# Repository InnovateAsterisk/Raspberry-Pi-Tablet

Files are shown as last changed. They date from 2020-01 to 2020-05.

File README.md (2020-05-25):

# Raspberry Pi Tablet

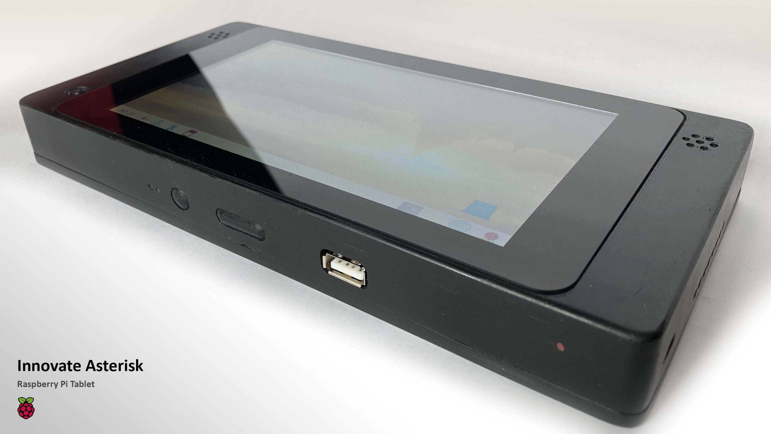
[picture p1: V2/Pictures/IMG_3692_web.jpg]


## Project Goals
To develop a 3D printable, Raspberry Pi based tablet. All parts (components) must be easy to obtain and readily available. It must have a battery, and it must be the primary source of power (meaning, it will charge up with a cable plugged in, but must have enough power to run without it.) It must be able to opperate perfect fine without a keyboard (meaning, everything in the user interface should work without an issue even if you dont have a keyboard and mouse plugged in.)

## Features
- **SBC :** Raspberry Pi version 4B+
- **Display :** 7 inch LCD Display (with touch)
- **Power Supply :** PiJuice UPS (with 5000 mAmp battery)
- **Camera :** Official Raspberry Pi 1080p Camera (front-facing)
- **Sound & Speakers:** Waveshare Audio HAT - powers 2 speakers, and 2 microphones, and provides an audio jack for headphones.
- **Accelerometer:** MPU-6050 Gyro/Accelerometer - to orientate the screen. (with python)
- **Cooling:** Fan connected to a Mosfet fan-speed controller (speed is controlled in python)
- **USB:** Breakout USB
- **Buttons:**
  - Power Button
  - Volume Up/Down rocker
- **LEDs**
  - Charge
  - Power and activity LED light is redirected (using nylon) to the case.
- **Backplate:** Bamboo wood back, with laser etched decal

## How To Video 
IMAGE ALT TEXT HERE (https://www.youtube.com/watch?v=wbJU22Zt_uo)

## Articles
- https://www.instructables.com/id/Raspberry-Pi-4B-3D-Printed-Tablet/
- https://www.hackster.io/news/innovate-asterisk-unveils-a-3d-printed-raspberry-pi-4-powered-tablet-be6d5298e047
- https://www.crackedconsole.com/2020/02/24/innovate-asterisk-unveils-a-3d-printed-raspberrypi-4-powered-tablet/

## Images
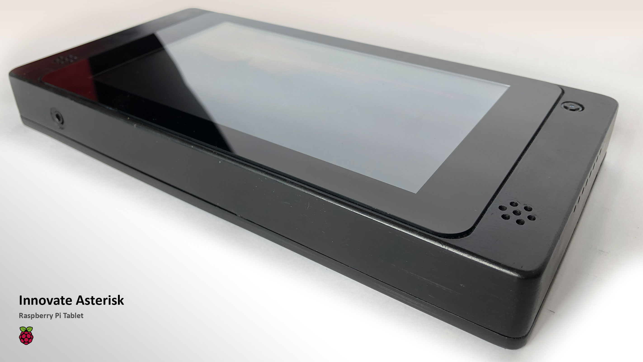
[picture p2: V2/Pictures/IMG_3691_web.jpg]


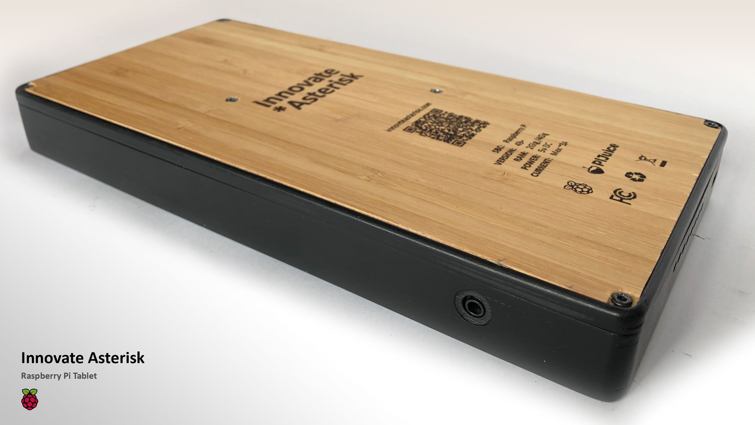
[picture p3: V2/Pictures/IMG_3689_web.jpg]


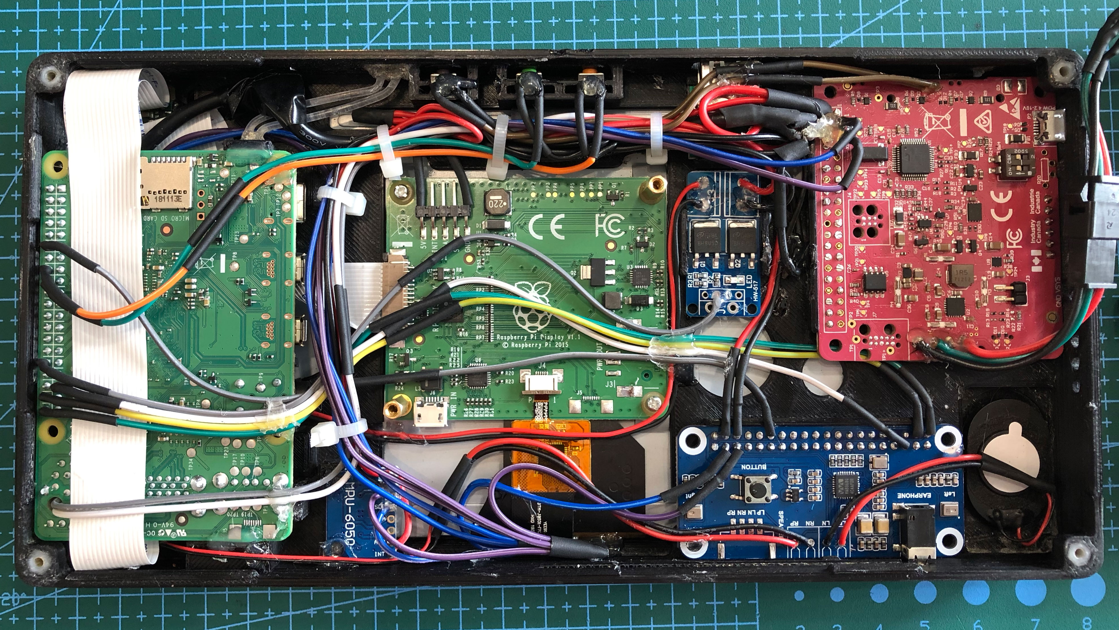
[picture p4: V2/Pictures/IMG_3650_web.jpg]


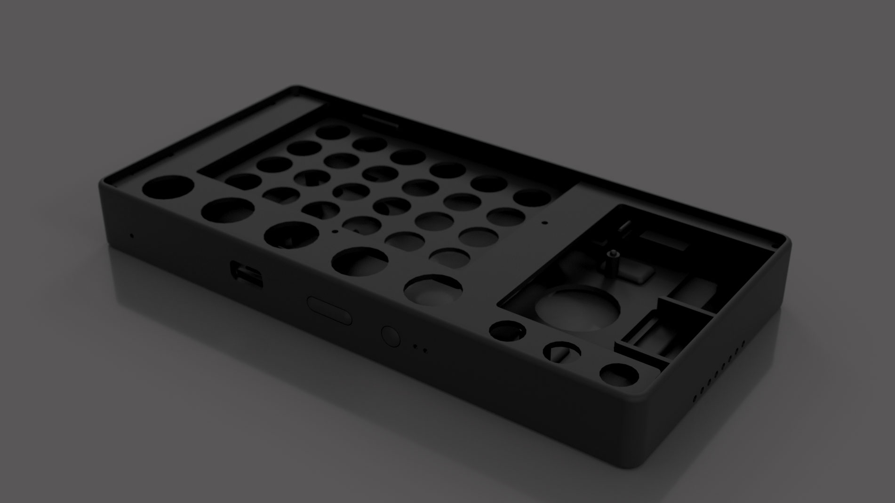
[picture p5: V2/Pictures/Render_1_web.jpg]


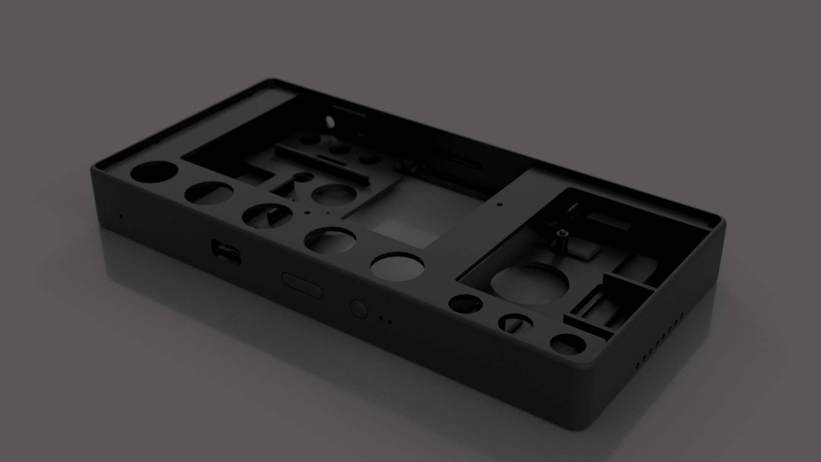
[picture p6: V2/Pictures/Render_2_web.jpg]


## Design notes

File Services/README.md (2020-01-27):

# Services

Various services will be needed in order to manage this device.

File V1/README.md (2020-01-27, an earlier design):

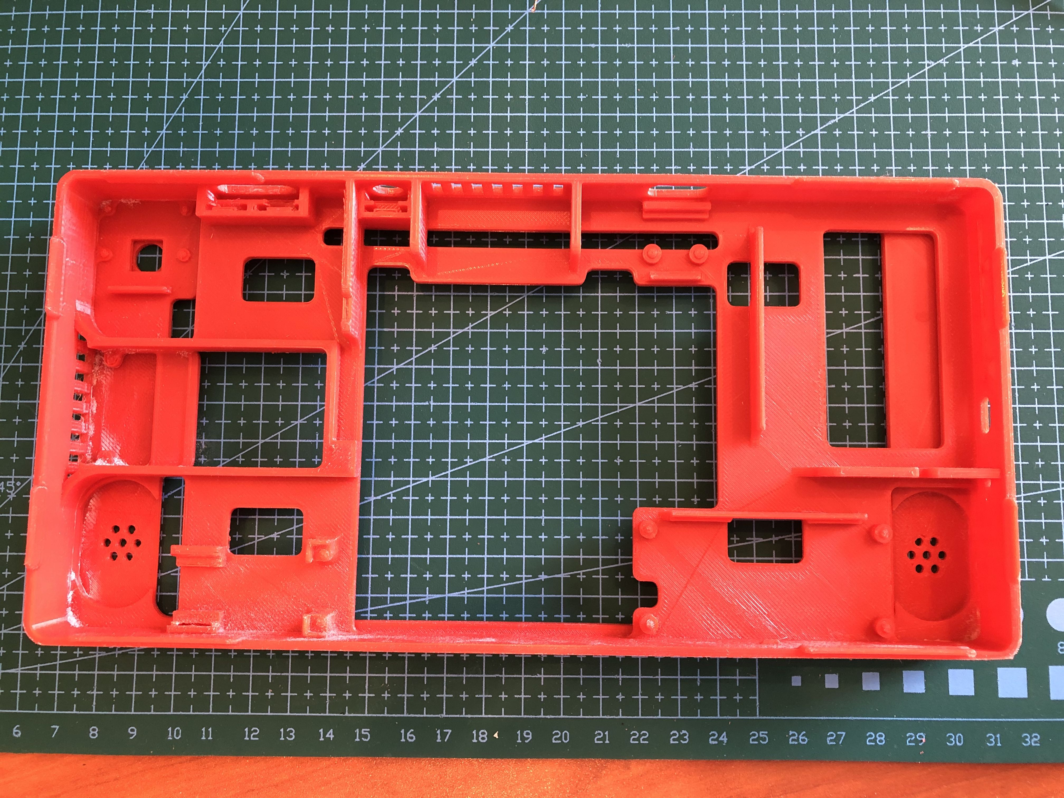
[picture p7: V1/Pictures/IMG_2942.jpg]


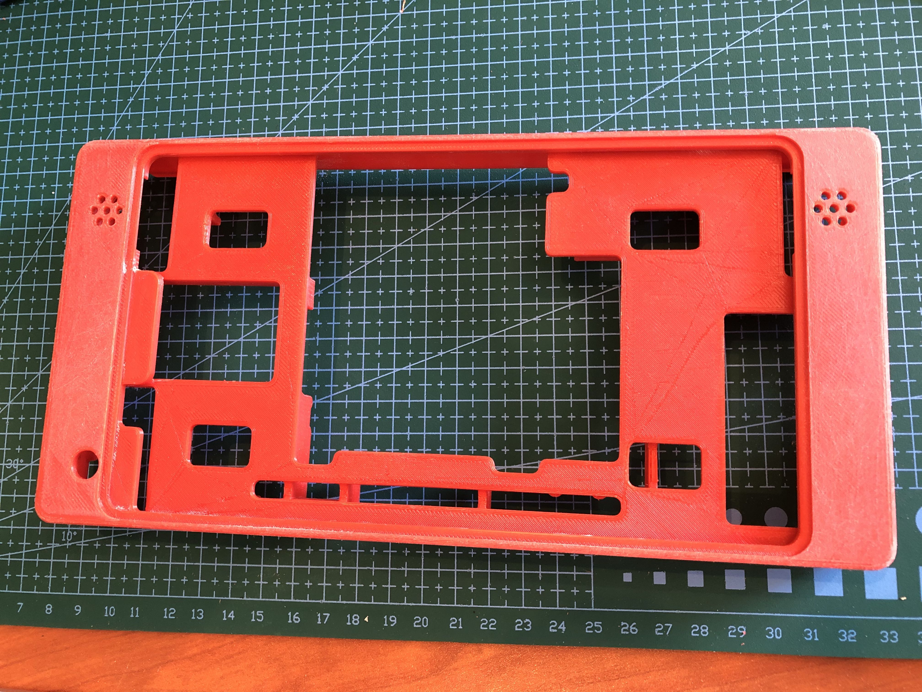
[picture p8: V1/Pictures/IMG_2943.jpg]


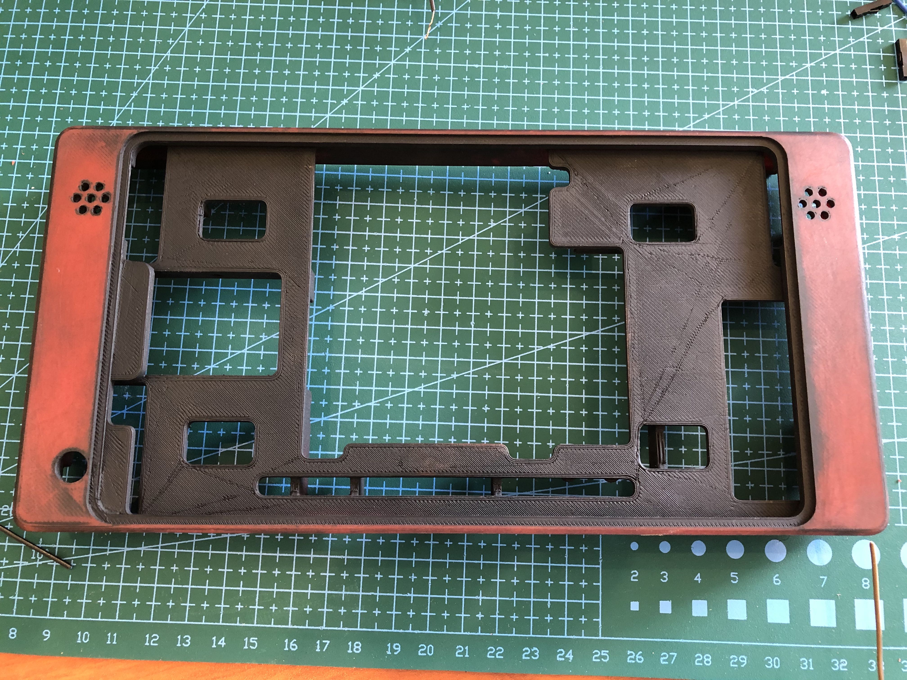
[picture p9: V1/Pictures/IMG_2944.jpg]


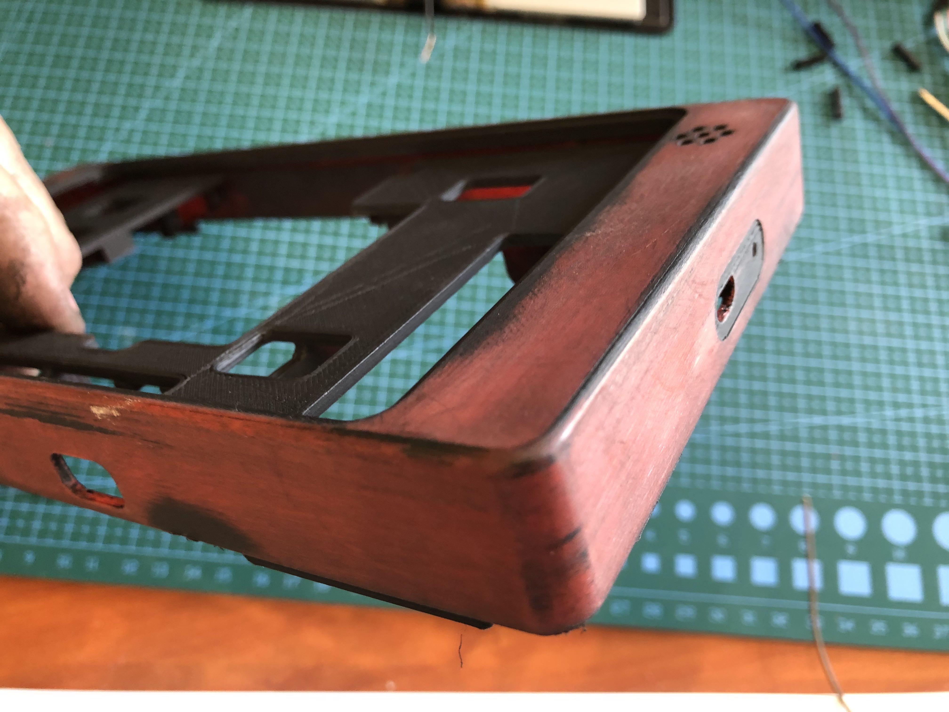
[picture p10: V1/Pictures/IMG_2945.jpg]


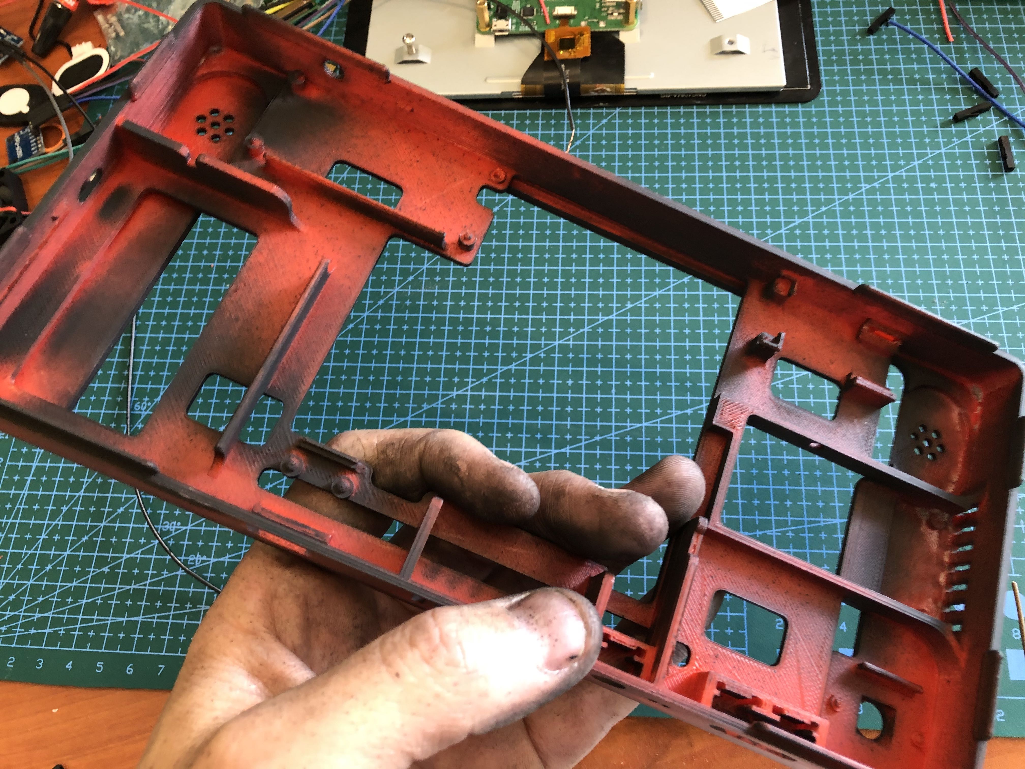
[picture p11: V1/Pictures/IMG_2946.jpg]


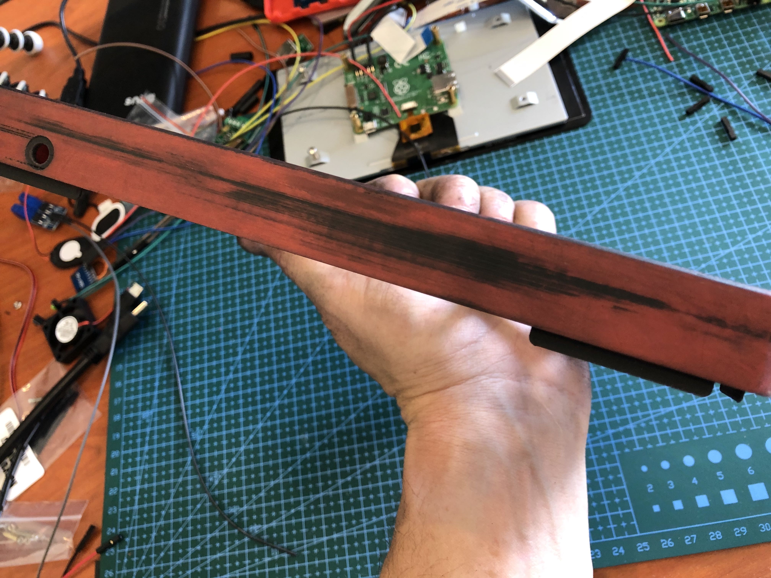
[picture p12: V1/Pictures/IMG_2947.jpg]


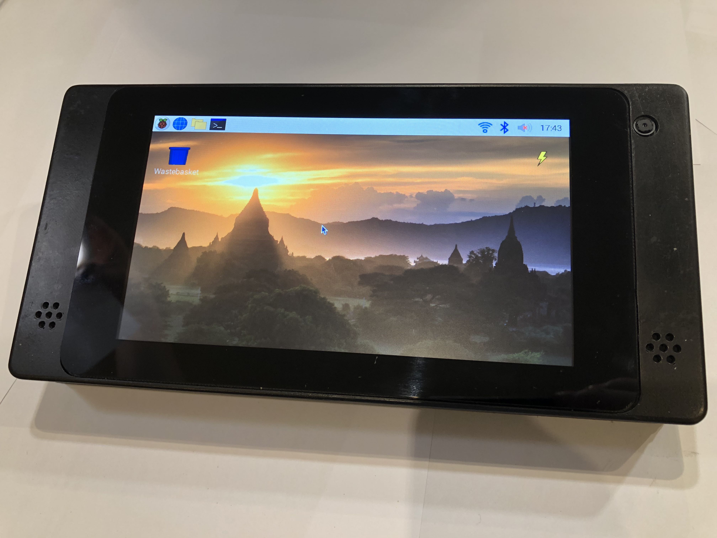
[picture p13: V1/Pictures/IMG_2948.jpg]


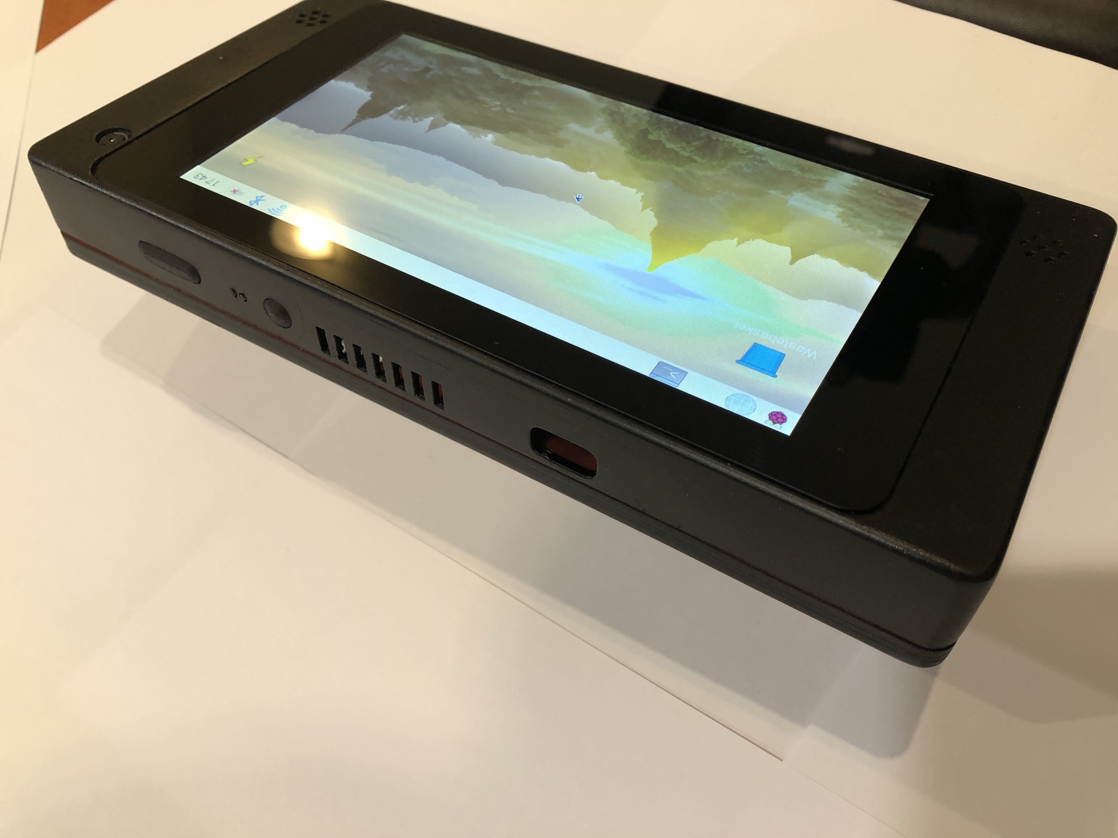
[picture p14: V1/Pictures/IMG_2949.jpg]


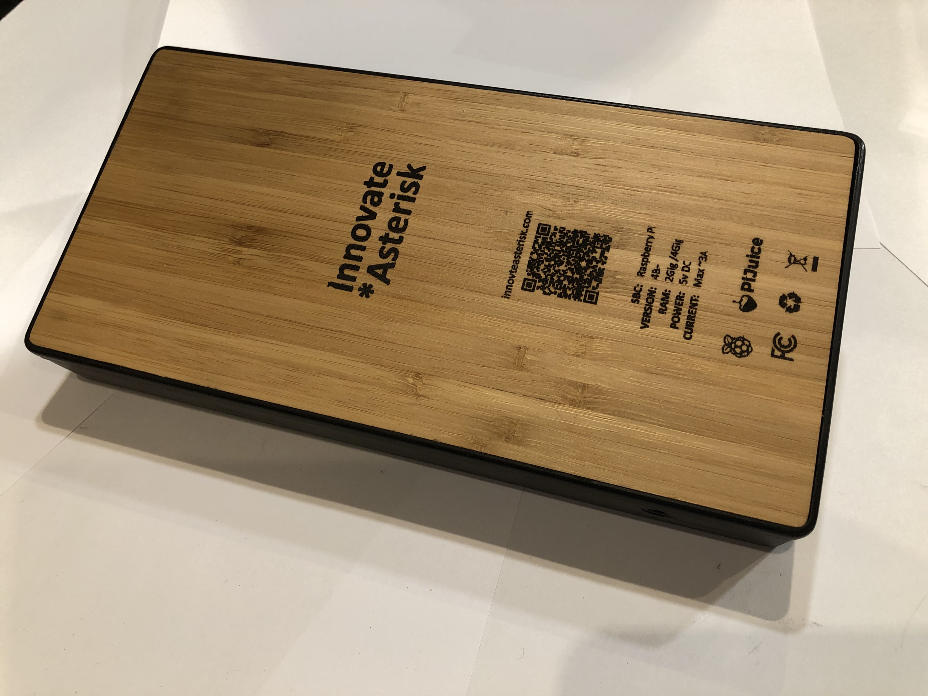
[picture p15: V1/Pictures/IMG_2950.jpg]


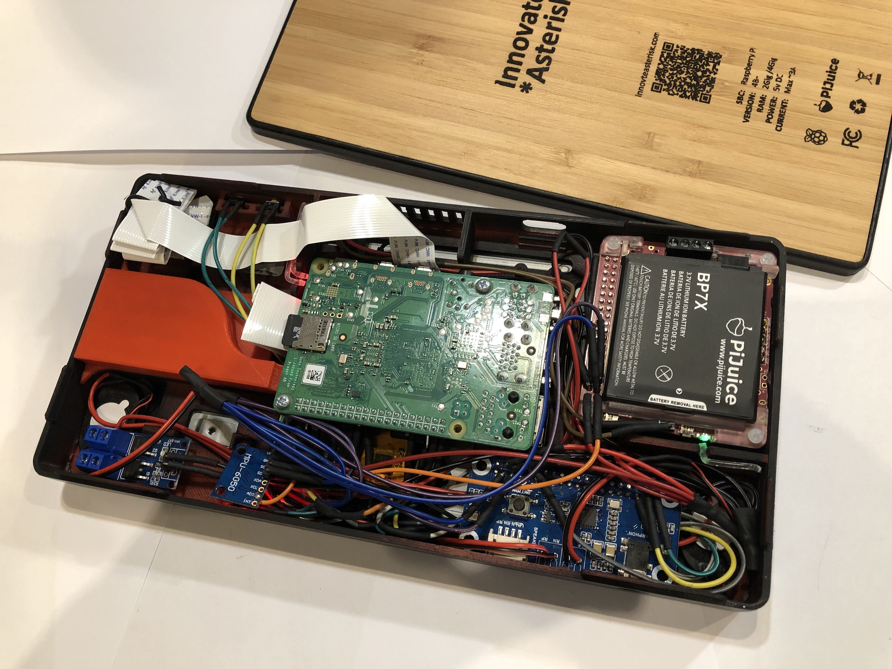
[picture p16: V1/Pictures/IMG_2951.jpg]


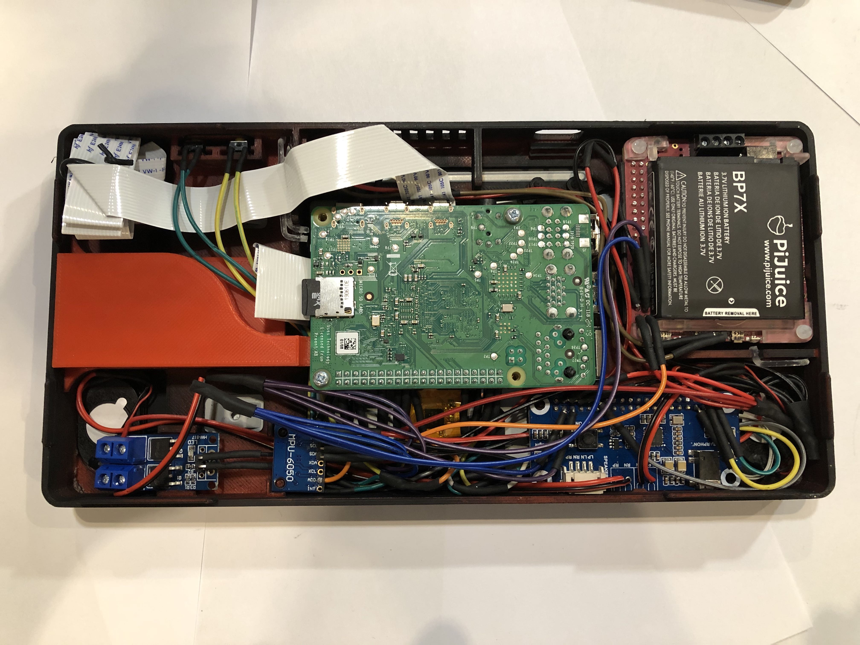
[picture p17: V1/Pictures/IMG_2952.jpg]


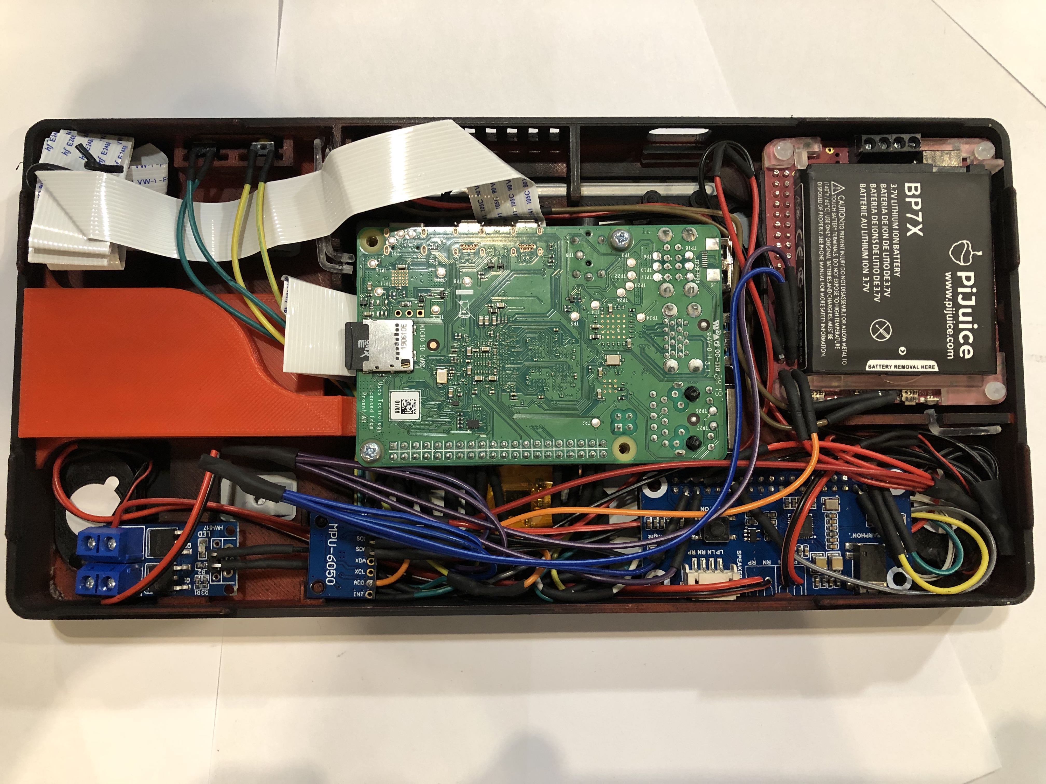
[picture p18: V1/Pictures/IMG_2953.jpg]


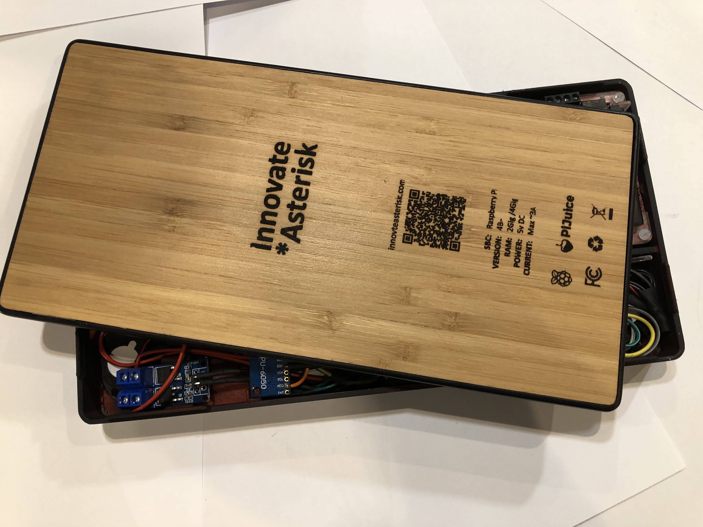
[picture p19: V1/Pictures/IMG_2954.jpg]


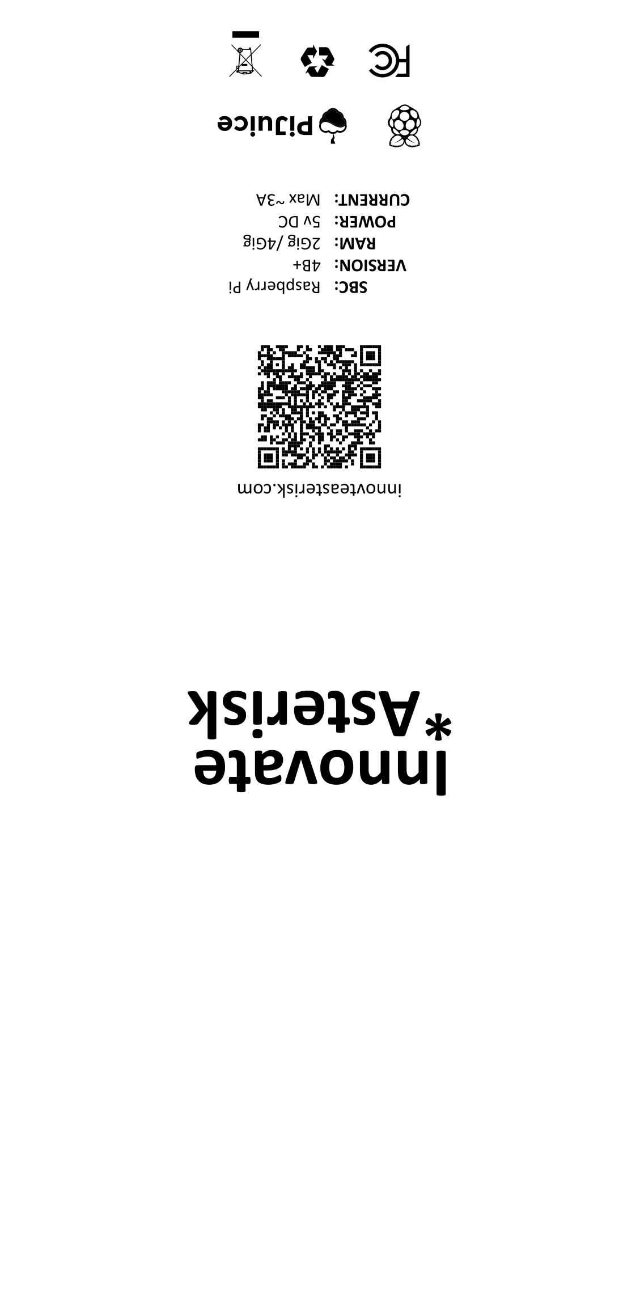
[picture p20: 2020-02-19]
Level_3_Wood/WoodDesign_ready.png

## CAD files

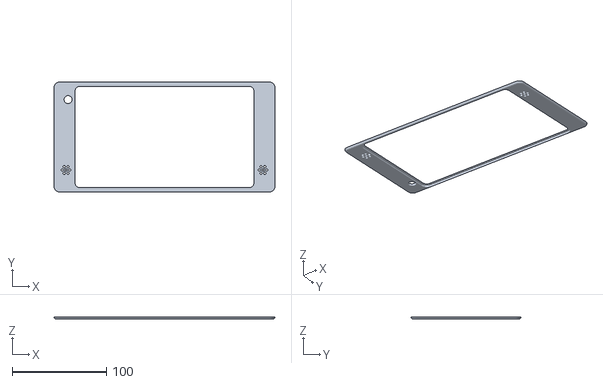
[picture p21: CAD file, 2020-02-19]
STL/Level_0.stl
234.4 x 116.6 x 2.20

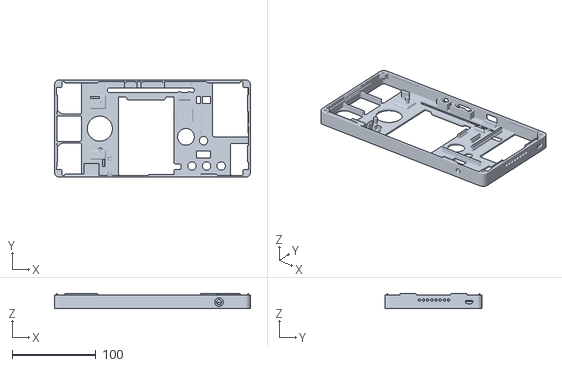
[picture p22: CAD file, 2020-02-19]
STL/Level_2.stl
234.4 x 116.6 x 17.8

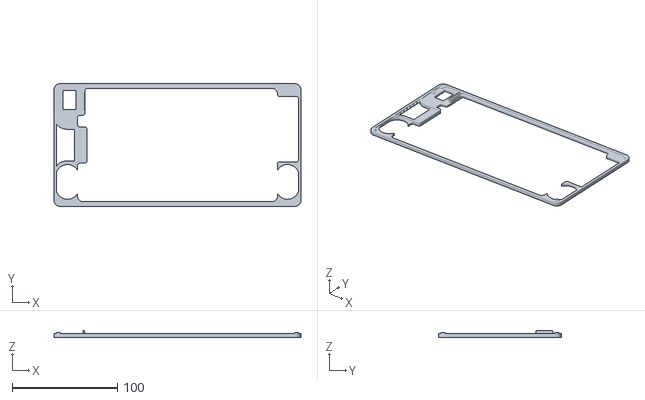
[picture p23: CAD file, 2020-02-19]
STL/Level_1.stl
234.4 x 116.6 x 6.77

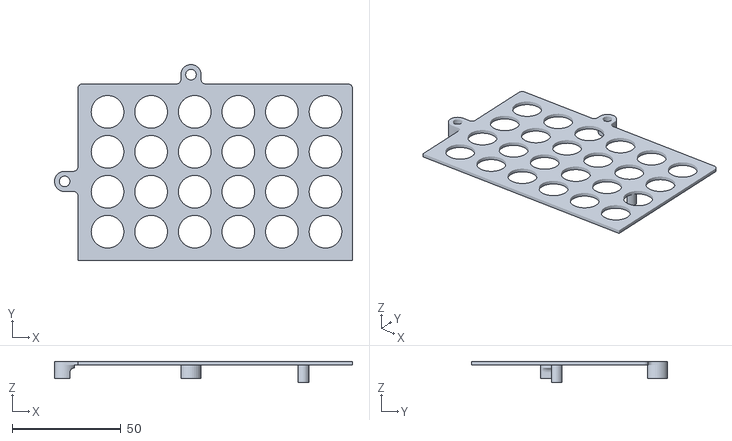
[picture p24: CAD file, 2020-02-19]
STL/Battery_Tray.stl
136.7 x 89.9 x 9.84

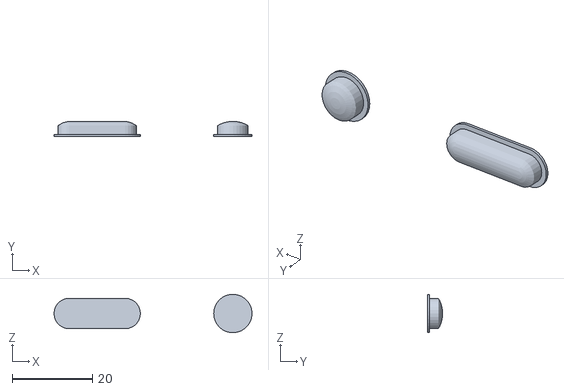
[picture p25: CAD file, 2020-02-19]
STL/Buttons.stl
49.5 x 3.70 x 9.59

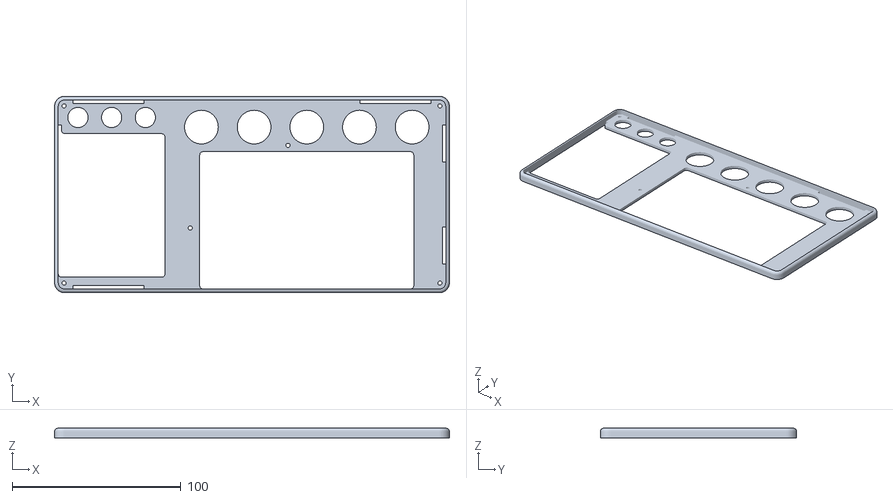
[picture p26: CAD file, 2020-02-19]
STL/Level_3.stl
234.4 x 116.6 x 5.70

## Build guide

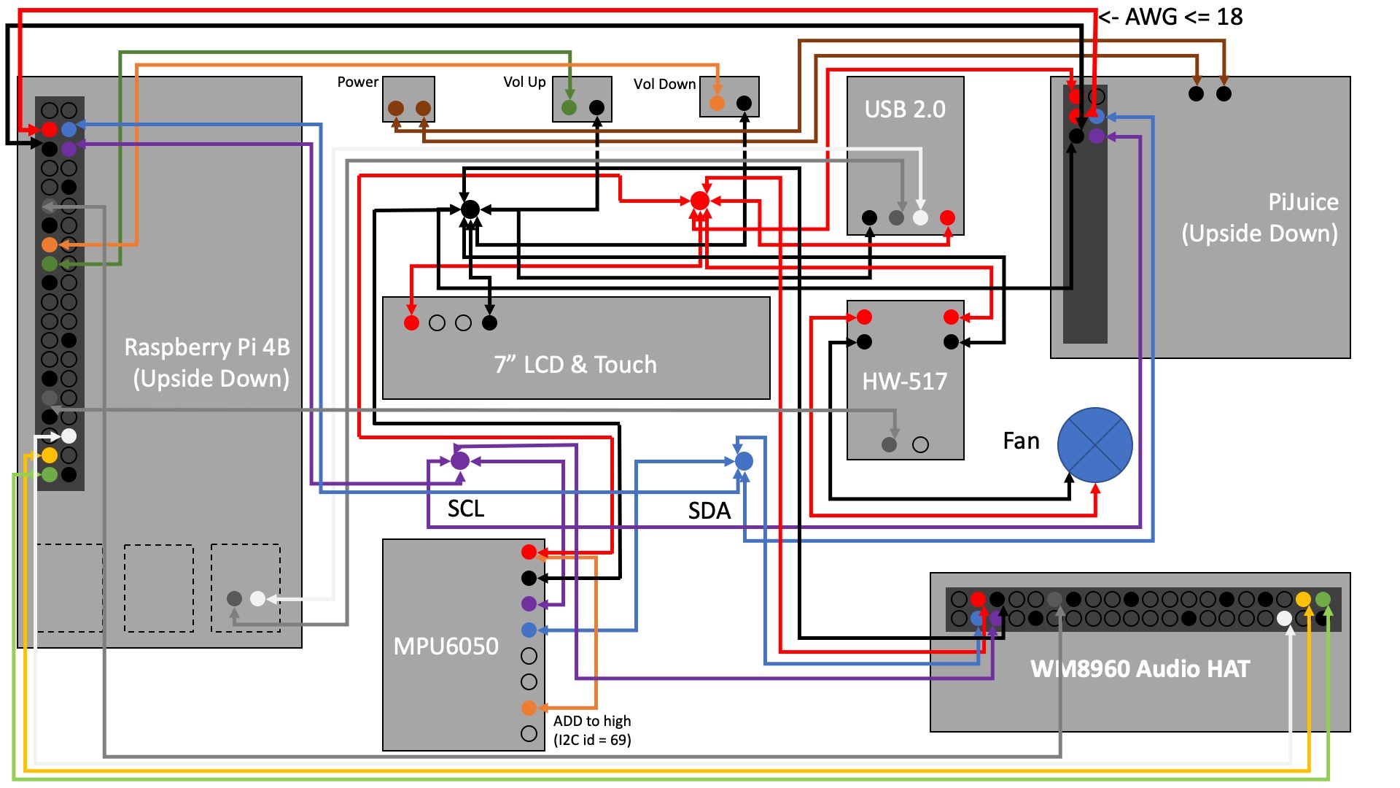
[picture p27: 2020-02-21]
Wiring Diagram/WiringDiagram.jpg

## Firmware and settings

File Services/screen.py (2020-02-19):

# Handles screen rotation using the Gyro
# ======================================

import smbus
import math
import time
import os

address = 0x69       # via i2cdetect (default is 68)

# Register https://www.i2cdevlib.com/devices/mpu6050#registers
PWR_MGMT_1   = 0x6B
SMPLRT_DIV   = 0x19
CONFIG       = 0x1A
GYRO_CONFIG  = 0x1B
ACCEL_CONFIG = 0x1C
INT_ENABLE   = 0x38
ACCEL_XOUT_H = 0x3B
ACCEL_YOUT_H = 0x3D
ACCEL_ZOUT_H = 0x3F
GYRO_XOUT_H  = 0x43
GYRO_YOUT_H  = 0x45
GYRO_ZOUT_H  = 0x47

# Pre-defined ranges
ACCEL_RANGE_2G = 0x00
ACCEL_RANGE_4G = 0x08
ACCEL_RANGE_8G = 0x10
ACCEL_RANGE_16G = 0x18

GYRO_RANGE_250DEG = 0x00
GYRO_RANGE_500DEG = 0x08
GYRO_RANGE_1000DEG = 0x10
GYRO_RANGE_2000DEG = 0x18

# Scale Modifiers
ACCEL_SCALE_MODIFIER_2G = 16384.0
ACCEL_SCALE_MODIFIER_4G = 8192.0
ACCEL_SCALE_MODIFIER_8G = 4096.0
ACCEL_SCALE_MODIFIER_16G = 2048.0

GYRO_SCALE_MODIFIER_250DEG = 131.0
GYRO_SCALE_MODIFIER_500DEG = 65.5
GYRO_SCALE_MODIFIER_1000DEG = 32.8
GYRO_SCALE_MODIFIER_2000DEG = 16.4

# Construct a SMBus
bus = smbus.SMBus(1)
bus.write_byte_data(address, PWR_MGMT_1, 0x00)
bus.write_byte_data(address, ACCEL_CONFIG, ACCEL_RANGE_2G)
bus.write_byte_data(address, GYRO_CONFIG, GYRO_RANGE_250DEG)

def read_byte(reg):
    return bus.read_byte_data(address, reg)

def read_word(reg):
    h = bus.read_byte_data(address, reg)
    l = bus.read_byte_data(address, reg+1)
    value = (h << 8) + l
    return value

def read_word_2c(reg):
    val = read_word(reg)
    if (val >= 0x8000): # -32768 +32768 
        return -((65535 - val) + 1)
    else:
        return val

def get_y_rotation(x,y,z):
    radians = math.atan2(x, math.sqrt((y*y)+(z*z)))
    return -math.degrees(radians)

def get_x_rotation(x,y,z):
    radians = math.atan2(y, math.sqrt((x*x)+(z*z)))
    return math.degrees(radians)

# ==============================

rotation = ""
while True:
        AX = []
        AY = []
        AZ = []
        for i in range(10):
                ax = 0
                ay = 0
                az = 0

                try:
                        ax = read_word_2c(ACCEL_XOUT_H) / ACCEL_SCALE_MODIFIER_2G
                        ay = read_word_2c(ACCEL_YOUT_H) / ACCEL_SCALE_MODIFIER_2G
                        az = read_word_2c(ACCEL_ZOUT_H) / ACCEL_SCALE_MODIFIER_2G
                except:
                        print("Error getting rotation")

                AX.append(ax)
                AY.append(ay)
                AZ.append(az)

                time.sleep(0.1)

        avg_x = sum(AX)/len(AX)
        avg_y = sum(AY)/len(AY)
        avg_z = sum(AZ)/len(AZ)

        r = round(get_y_rotation(avg_x, avg_y, avg_z))

        if r >= -20 and r <= 20:
                # Normal
                if(rotation != "normal"):
                        rotation = "normal"
                        print("Screen Rotate: Normal")
                        os.popen("xrandr -display :0.0 --output DSI-1 --rotate normal")
                        os.popen("DISPLAY=:0 xinput --set-prop 'FT5406 memory based driver' 'Coordinate Transformation Matrix' 0 0 0 0 0 0 0 0 0")
        elif r < -20:
                # You rotate Left (Set Screen to Right)
                if(rotation != "left"):
                        rotation = "left"
                        print("Screen Rotate Left")
                        os.popen("xrandr -display :0.0 --output DSI-1 --rotate right")
                        os.popen("DISPLAY=:0 xinput --set-prop 'FT5406 memory based driver' 'Coordinate Transformation Matrix' 0 1 0 -1 0 1 0 0 1")
        elif r > 20:
                # You rotate Right (Set Screen Left)
                if(rotation != "right"):
                        rotation = "right"
                        print("Screen Rotate Right")
                        os.popen("xrandr -display :0.0 --output DSI-1 --rotate left")
                        os.popen("DISPLAY=:0 xinput --set-prop 'FT5406 memory based driver' 'Coordinate Transformation Matrix' 0 -1 1 1 0 0 0 0 1")
        else: 
                # Rotate 180
                if(rotation != "inverted"):
                        rotation = "inverted"
                        print("Rotate 180")
                        os.popen("xrandr -display :0.0 --output DSI-1 --rotate inverted")
                        os.popen("DISPLAY=:0 xinput --set-prop 'FT5406 memory based driver' 'Coordinate Transformation Matrix' -1 0 1 0 -1 1 0 0 1")

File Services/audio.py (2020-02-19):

# Handles the Volume Up/down and the Headphone Jack
# =================================================


import RPi.GPIO as GPIO
import sys
import time
import os
import alsaaudio

# print alsaaudio.cards()        # If we uninstall the primary card, this list is empty
# print alsaaudio.mixers() # [Speaker][Master][Capture]
MasterMixer = alsaaudio.Mixer("Speaker")

IS_JACK_IN = False      # If the headphone jack is n use (TODO)
VOL_UP_GPIO_PIN = 24    # The GPIO pin (BCM) for Volume Up (Green)
VOL_DOWN_GPIO_PIN = 23  # The GPIO pin (BCM) for Volume Down (Yellow)

# Setup GPIO
GPIO.setmode(GPIO.BCM)
GPIO.setup(VOL_UP_GPIO_PIN, GPIO.IN, pull_up_down=GPIO.PUD_UP)
GPIO.setup(VOL_DOWN_GPIO_PIN, GPIO.IN, pull_up_down=GPIO.PUD_UP)

def IncreaseVolume():
    # Get the current volume
    v = MasterMixer.getvolume()[0]
    if v >= 100:
        print("Max Volume!")
        return
    else:
        if v > 95: v = 95
        print("Increase Volume from "+ str(v) +" to "+ str(v+5) +"")
        MasterMixer.setvolume(v+5) 
        return

def DecreaseVolume():
    # Get the current volume
    v = MasterMixer.getvolume()[0]
    if v <= 0:
        print("Min Volume!")
        return
    else:
        if v < 5: v = 5
        print("Decrease Volume from "+ str(v)  +" to "+ str(v-5) +"")
        MasterMixer.setvolume(v-5)
        return

def button_volume(pin):
    # Identify Direction
    if pin == VOL_UP_GPIO_PIN:
        IncreaseVolume()
    elif pin == VOL_DOWN_GPIO_PIN:
        DecreaseVolume()
    else:
        print("Unknown PIN")

GPIO.add_event_detect(VOL_UP_GPIO_PIN, GPIO.FALLING, callback=button_volume, bouncetime=1000)
GPIO.add_event_detect(VOL_DOWN_GPIO_PIN, GPIO.FALLING, callback=button_volume, bouncetime=1000)

while True: # Run forever
    # Together
    if (GPIO.input(VOL_UP_GPIO_PIN) == False and GPIO.input(VOL_DOWN_GPIO_PIN) == False):
        print("Both buttons press together... not sure what to do")
    else:
        # Vol Up
        if GPIO.input(VOL_UP_GPIO_PIN) == False:
            IncreaseVolume()
        # Vol Down
        if GPIO.input(VOL_DOWN_GPIO_PIN) == False:
            DecreaseVolume()

    # Slow
    time.sleep(0.1)

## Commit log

2020-02-06 General Updates and Fixes
    [audio.py, screen.py]
2020-02-19 Added STL and GCODE
    [Battery_Tray.stl, Buttons.stl, Level_0.stl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]
2020-02-21 Wiring Diagram
